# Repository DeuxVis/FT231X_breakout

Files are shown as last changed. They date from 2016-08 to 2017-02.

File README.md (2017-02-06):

## Intro

This is a breakout board for the USB to UART (serial) chip FT231X from FTDI.

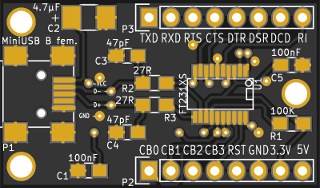
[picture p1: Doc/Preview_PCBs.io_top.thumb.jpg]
Board Preview Board top as previewed on PCBs.io


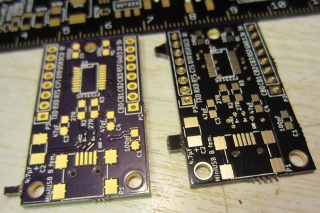
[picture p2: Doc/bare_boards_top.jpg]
Boards Top Board top as made by OSHPark and PCBs.io

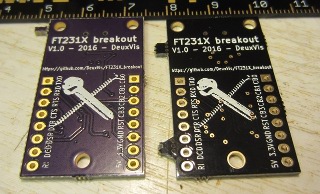
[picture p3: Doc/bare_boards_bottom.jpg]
Boards Bottom Board bottom as made by OSHPark and PCBs.io


## Example uses

*   For prototyping purpose with that IC - I'm curious about the CBUS pins possibilities.
*   Or for straight use as a 3.3V - 5V tolerant - USB to serial converter, for instance to program some µcontrollers (ESP8266 anyone ?).

## I want some !

Shared on those fabrication services :

* [PCBs.io](https://PCBs.io/share/rwxDz) a little cheaper.
* [OSH Park](https://oshpark.com/shared_projects/f9qFRt6w) purpler.

Not fully tested yet, quick test seems to indicate they work fine. What has been tested to work :

* CBUS IO.
* Talking to an arduino through the serial interface.

## Motivation

I needed this breakout board to prototype a project of mine which would involve that FTDI chip.

I could have used the nice [sparkfun breakout](https://www.sparkfun.com/products/11736), but I also wanted to rank up my Kicad skills - this is my first "serious" Kicad project.

## Documentation

Nothing yet.

You can probably use some informations from the great [datasheet from FTDI](http://www.ftdichip.com/Support/Documents/DataSheets/ICs/DS_FT231X.pdf).

This breakout is an implementation of the first sample application from that document.

## License



This work is licensed under a [Creative Commons Attribution-ShareAlike 3.0 Unported](https://creativecommons.org/licenses/by-sa/3.0/) License - aka CC BY-SA 3.0.

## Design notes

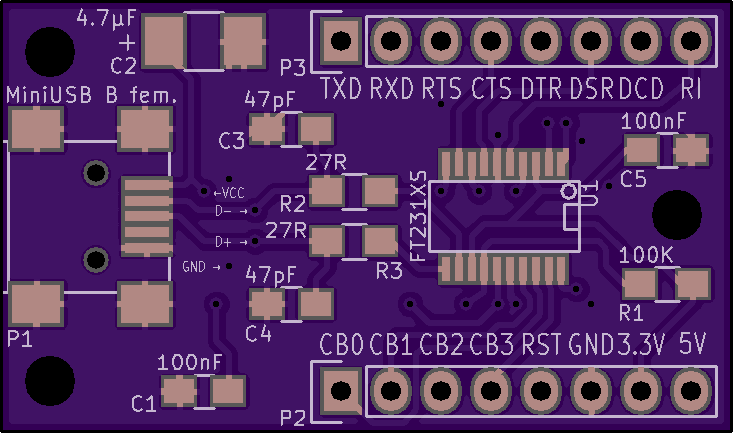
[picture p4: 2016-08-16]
Doc/Preview_OSH_Park_top.png

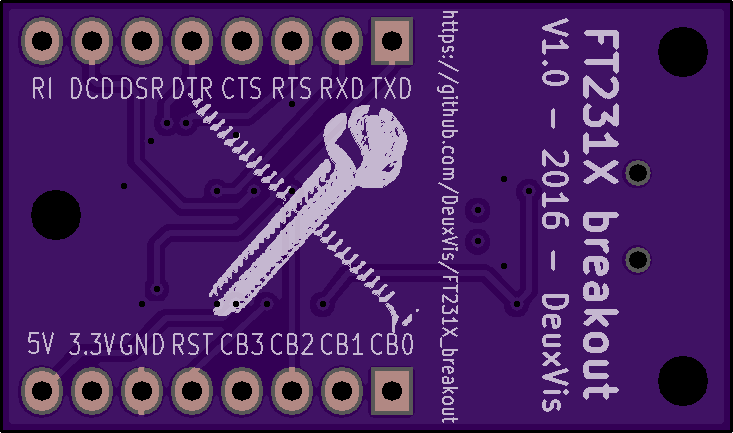
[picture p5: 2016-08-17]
Doc/Preview_OSH_Park_bottom.png

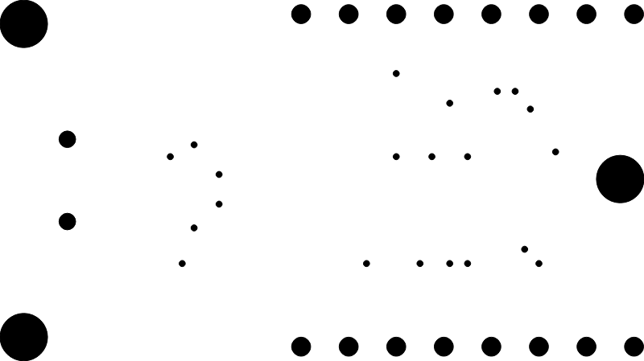
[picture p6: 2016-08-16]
Doc/Preview_PCBs.io_drl.png

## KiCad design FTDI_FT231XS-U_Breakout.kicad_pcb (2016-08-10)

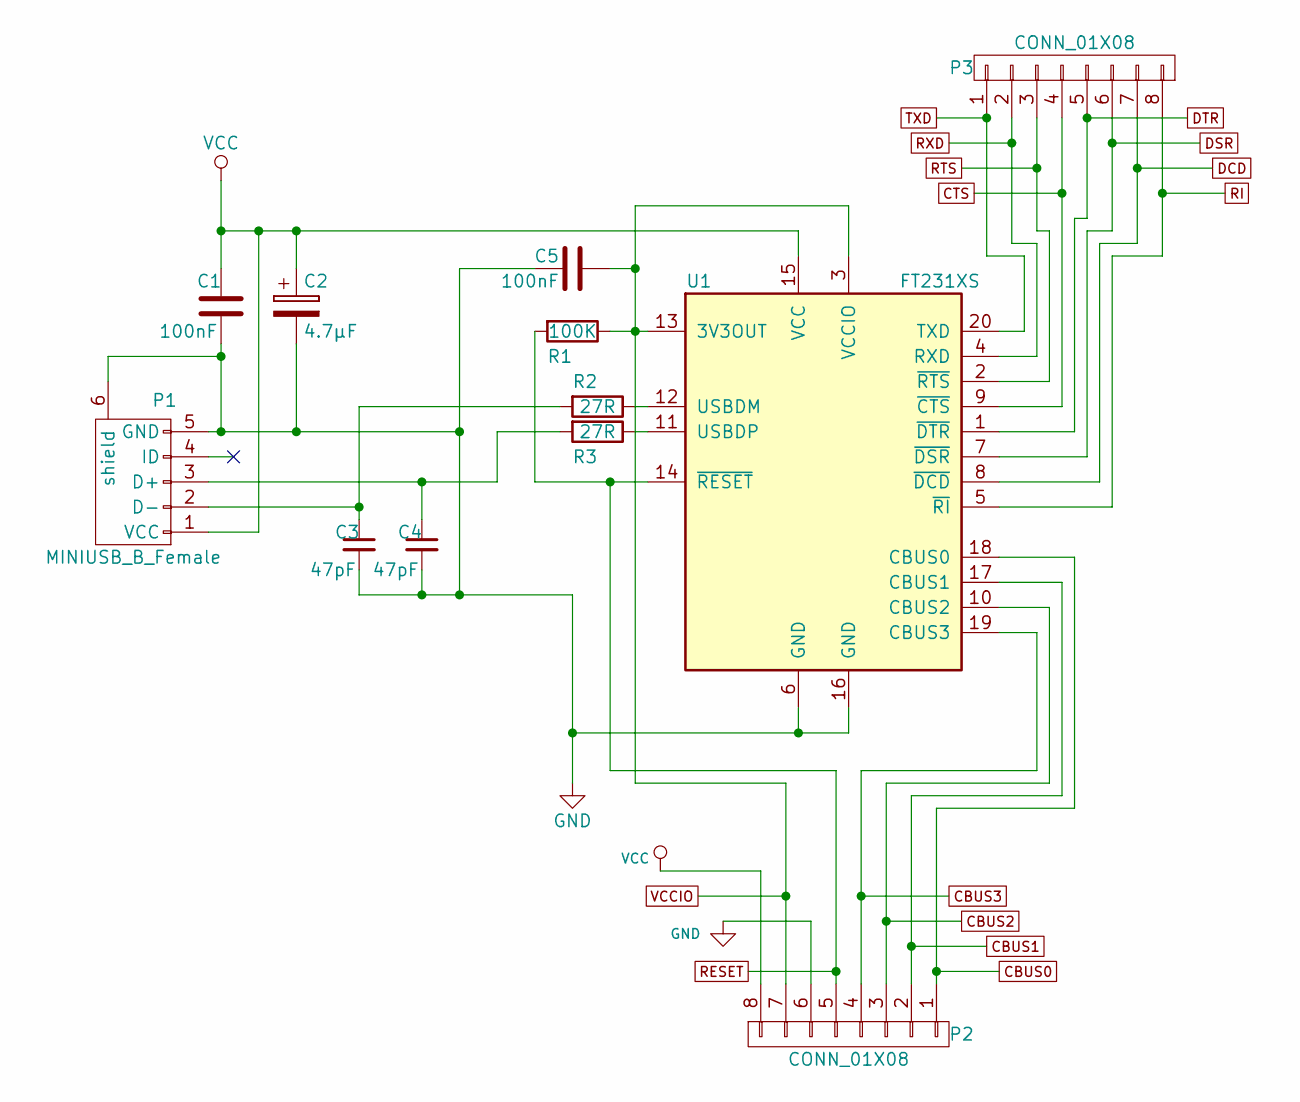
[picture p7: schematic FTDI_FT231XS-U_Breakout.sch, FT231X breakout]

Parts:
C1, C5: 100nF; C_0805_HandSoldering
C2: 4.7µF; C_1210_HandSoldering
C3, C4: 47pF; C_0805_HandSoldering
P1: MINIUSB_B_Female; USB_Mini-B
P2, P3: CONN_01X08; Pin_Header_Straight_1x08
R1: 100K; R_0805_HandSoldering
R2, R3: 27R; R_0805_HandSoldering
U1: FT231XS; SSOP-20

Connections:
CBUS0: P2.1, U1.18 (CBUS0)
CBUS1: P2.2, U1.17 (CBUS1)
CBUS2: P2.3, U1.10 (CBUS2)
CBUS3: P2.4, U1.19 (CBUS3)
CTS: P3.4, U1.9 (~CTS)
DCD: P3.7, U1.8 (~DCD)
DSR: P3.6, U1.7 (~DSR)
DTR: P3.5, U1.1 (~DTR)
GND: C1.2, C2.2, C3.2, C4.2, C5.1, P1.5 (GND), P1.6 (shield), P2.6, U1.6 (GND), U1.16 (GND)
unnamed: C3.1, P1.2 (D-), R2.2
unnamed: C4.1, P1.3 (D+), R3.2
unnamed: R2.1, U1.12 (USBDM)
unnamed: R3.1, U1.11 (USBDP)
RESET: P2.5, R1.2, U1.14 (~RESET)
RI: P3.8, U1.5 (~RI)
RTS: P3.3, U1.2 (~RTS)
RXD: P3.2, U1.4 (RXD)
TXD: P3.1, U1.20 (TXD)
VCC: C1.1, C2.1, P1.1 (VCC), P2.8, U1.15 (VCC)
VCCIO: C5.2, P2.7, R1.1, U1.3 (VCCIO), U1.13 (3V3OUT)

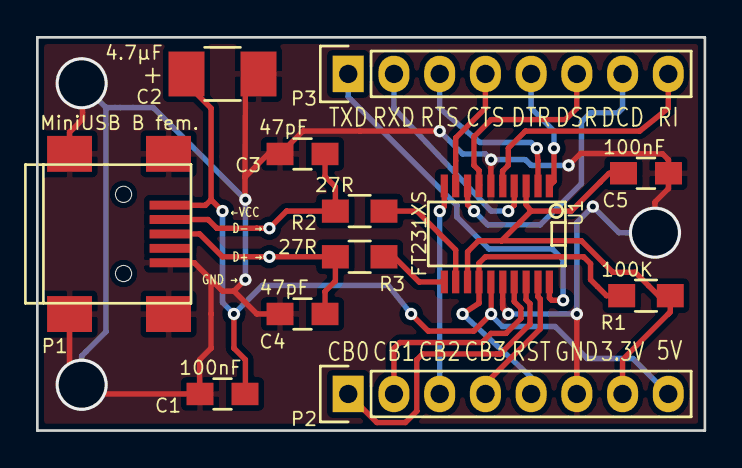
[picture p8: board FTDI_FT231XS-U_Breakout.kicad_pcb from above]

Board: 2 copper layers, 37.1 x 21.8 mm, 12 parts (0 on the bottom side), 20 nets.

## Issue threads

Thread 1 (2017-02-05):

I'm curious about the CBUS pins possibilities.

madeintheusb, 2017-02-05:
The FT231X and the FT232R as well a have very interesting and not well documented named Synchronous bit banging. CBUS will always be limited to 4 IO.
See my device www.Nusbio.net. At some point I used an FT231X but came back to the FT232RL because I do not want to do the reflow  myself.

DeuxVis, 2017-02-06:
Well theoretically - I didn't test that yet - you could expand that to 8 IO with some simple glue logic : using 3 bits for address and 1 for data.

To be honest I only used FT231X because that's what I had in stock, and being limited to 4 bits was not a problem for my application.

Closed 2017-02-06.

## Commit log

2016-08-10 First commit : Import of project.
    [FTDI_FT231XS-U_Breakout.kicad_pcb, FTDI_FT231XS-U_Breakout.sch]
2016-08-16 Adding gerbers for PCBs.io fabrication service.
    [FTDI_FT231XS-U_Breakout-B.Cu.gbl, FTDI_FT231XS-U_Breakout-B.Mask.gbs, FTDI_FT231XS-U_Breakout-B.SilkS.gbo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]
